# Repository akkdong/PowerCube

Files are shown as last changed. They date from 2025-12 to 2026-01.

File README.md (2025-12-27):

PowerCube
- Power Bank
- GPS
- Variometer
- Bluetooth

Goal: Charge mobile phone while transmitting GPS & Variometer data. It can also support BT connectivity.

<br>
<br>
<center>
  <p>
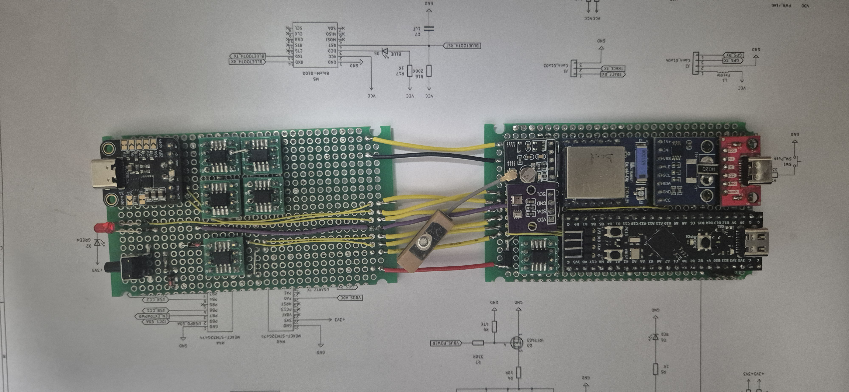
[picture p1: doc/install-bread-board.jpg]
    
  </p>
  <p>
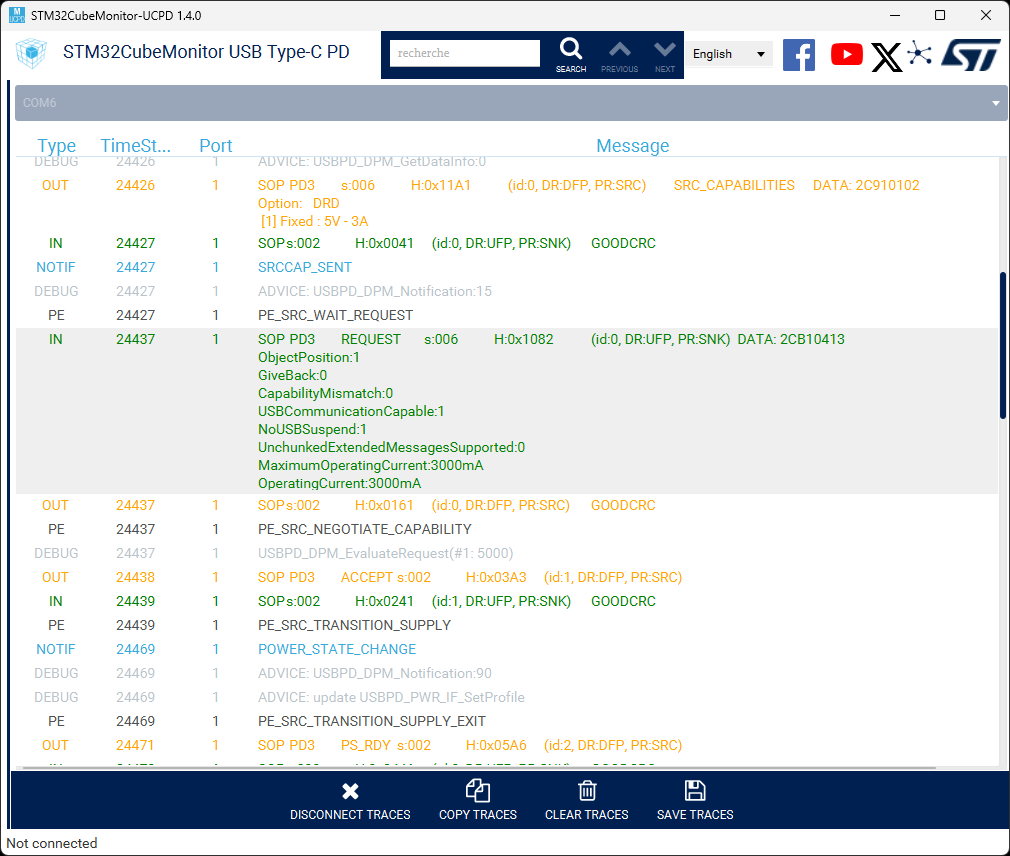
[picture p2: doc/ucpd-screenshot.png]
    
  </p>
  <p>
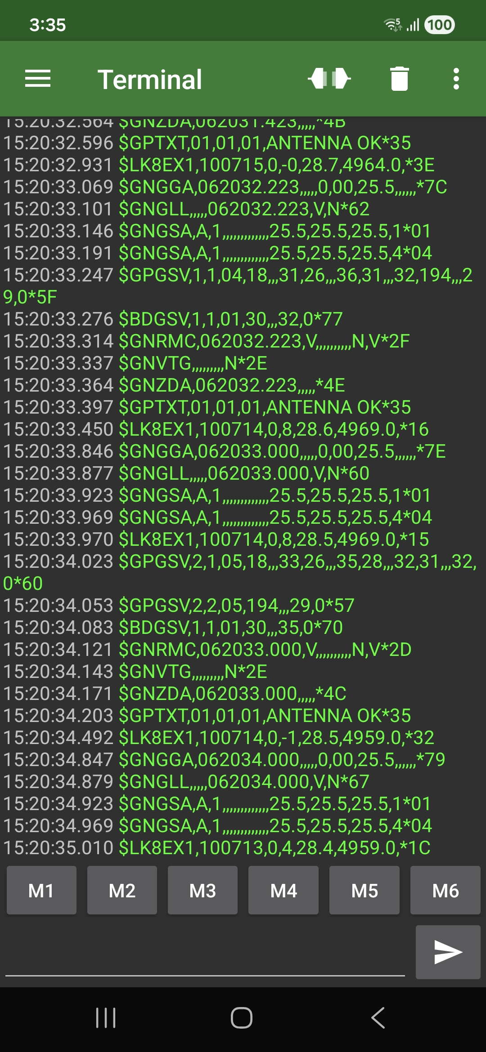
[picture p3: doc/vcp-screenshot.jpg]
    
  </p>
  <p>
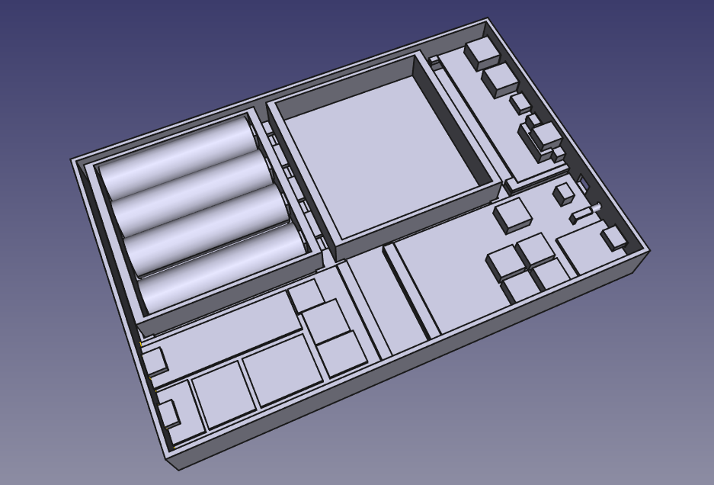
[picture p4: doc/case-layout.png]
    
  </p>
  <p>
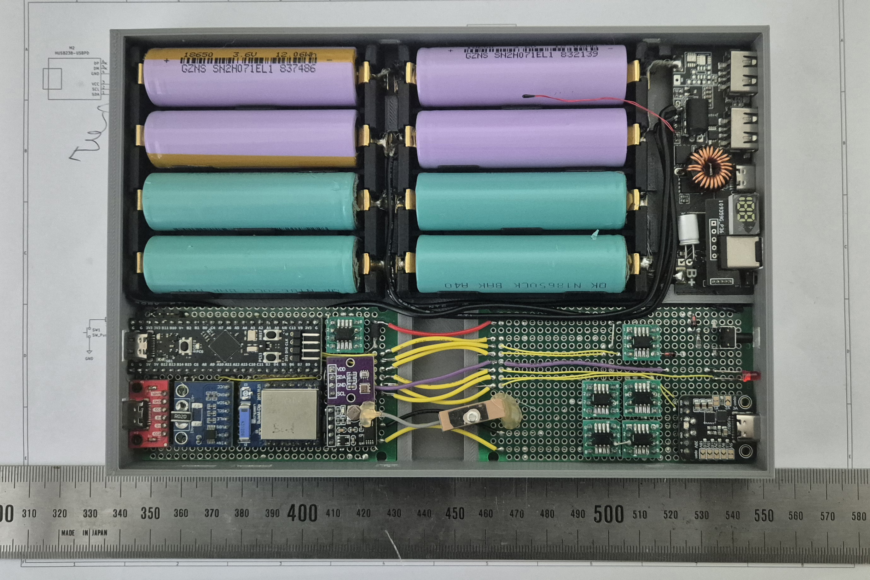
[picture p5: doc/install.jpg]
    
  </p>
</center>

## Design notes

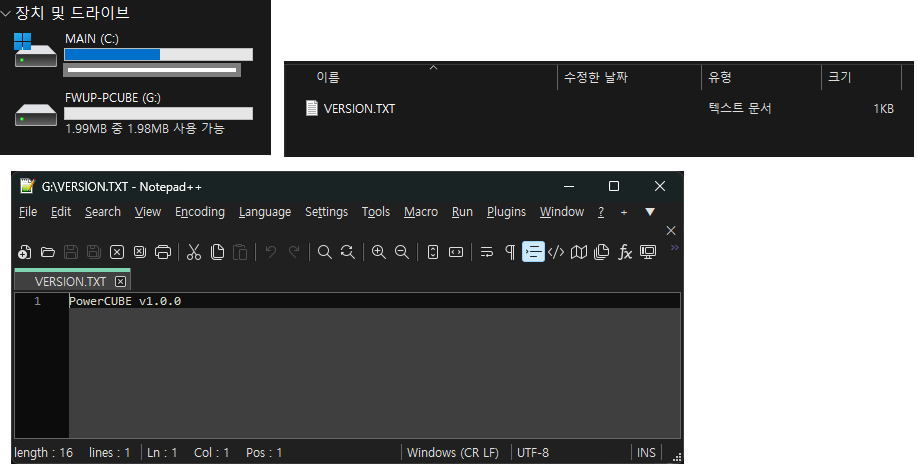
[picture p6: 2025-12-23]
doc/MSC-Bootloader.png

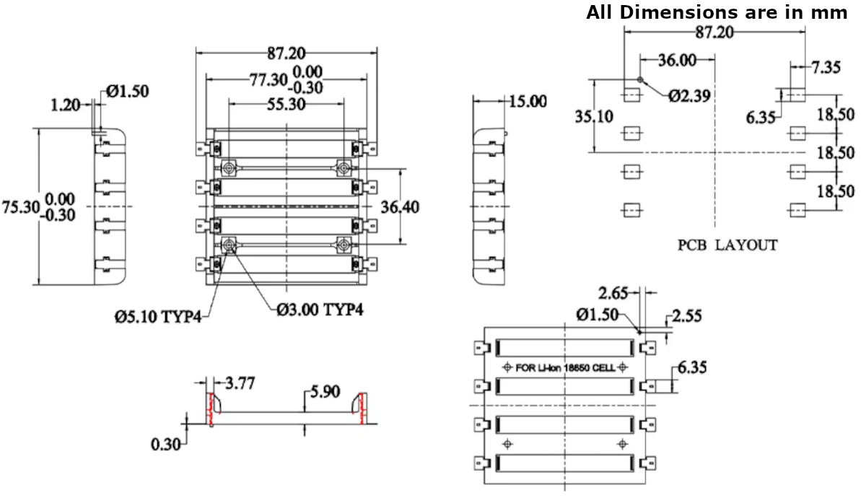
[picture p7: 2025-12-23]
doc/4_X_18650_Cell_Lithium_Ion_Battery_Holder_SMT_SMD_Socket_1_.jpg

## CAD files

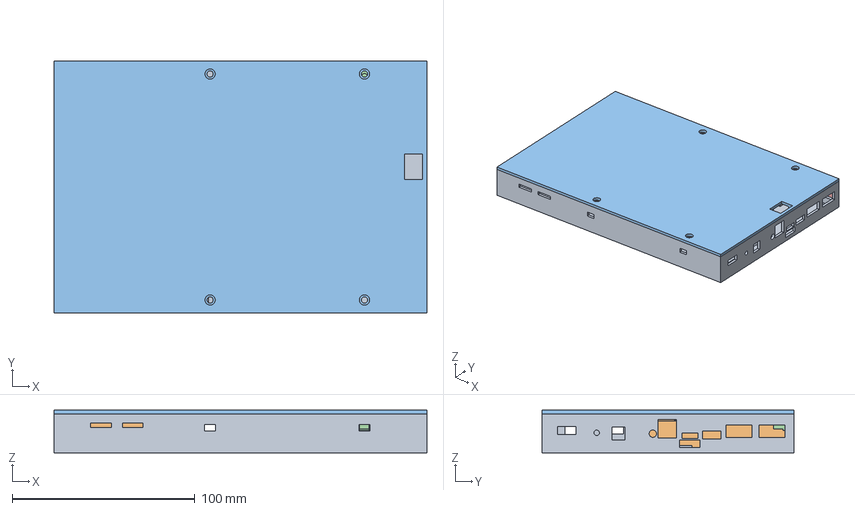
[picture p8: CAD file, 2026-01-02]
hw/enclosure/enclosure.FCStd
204.0 x 138.0 x 23.4 mm
ENCLOSUER-BODY
BatHolder-Left
ENCLOSUER-COVER
FixGuide
SPACER-A
SPACER-B

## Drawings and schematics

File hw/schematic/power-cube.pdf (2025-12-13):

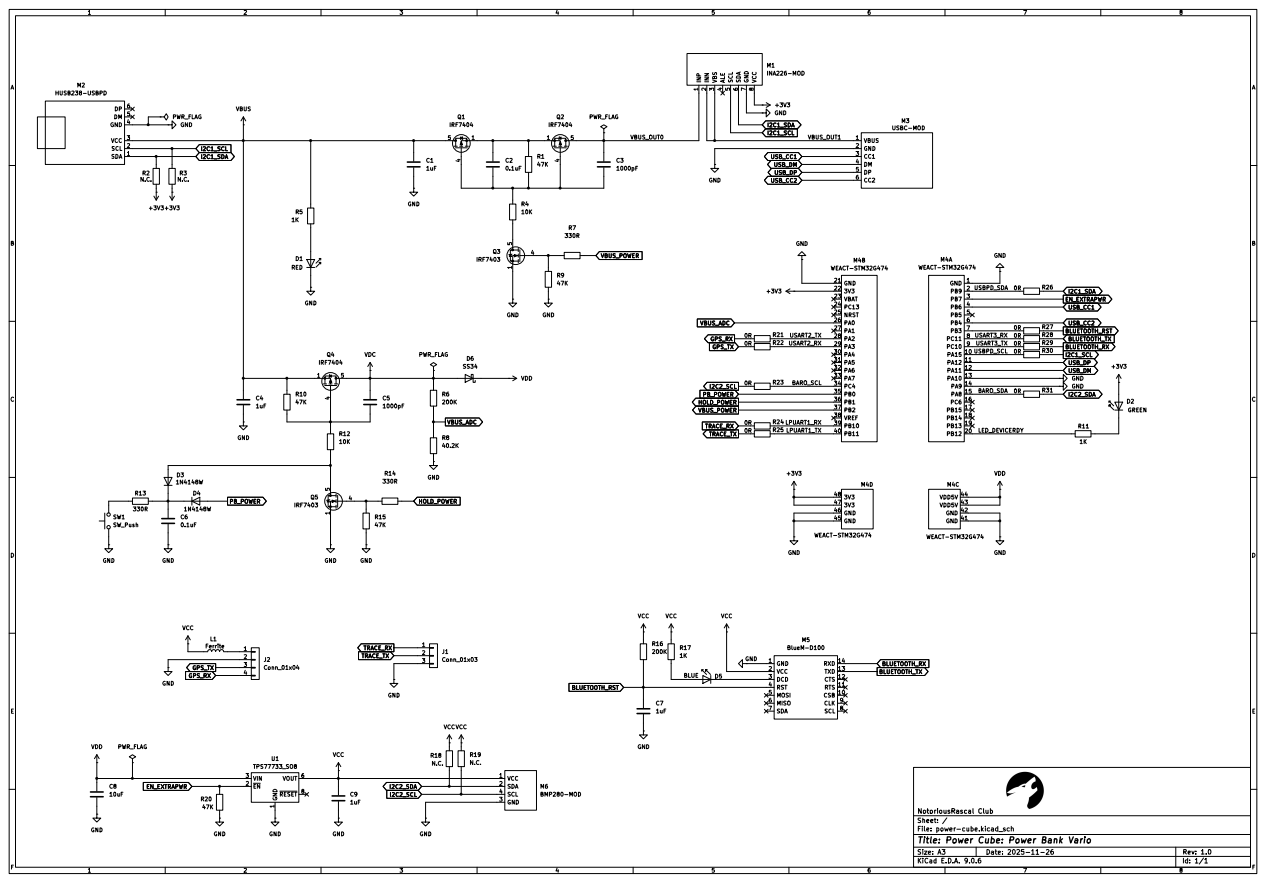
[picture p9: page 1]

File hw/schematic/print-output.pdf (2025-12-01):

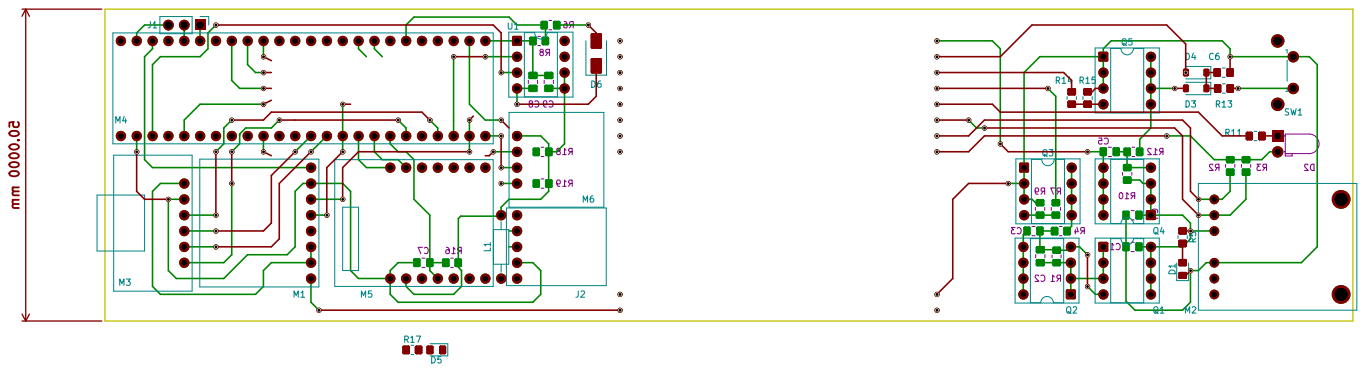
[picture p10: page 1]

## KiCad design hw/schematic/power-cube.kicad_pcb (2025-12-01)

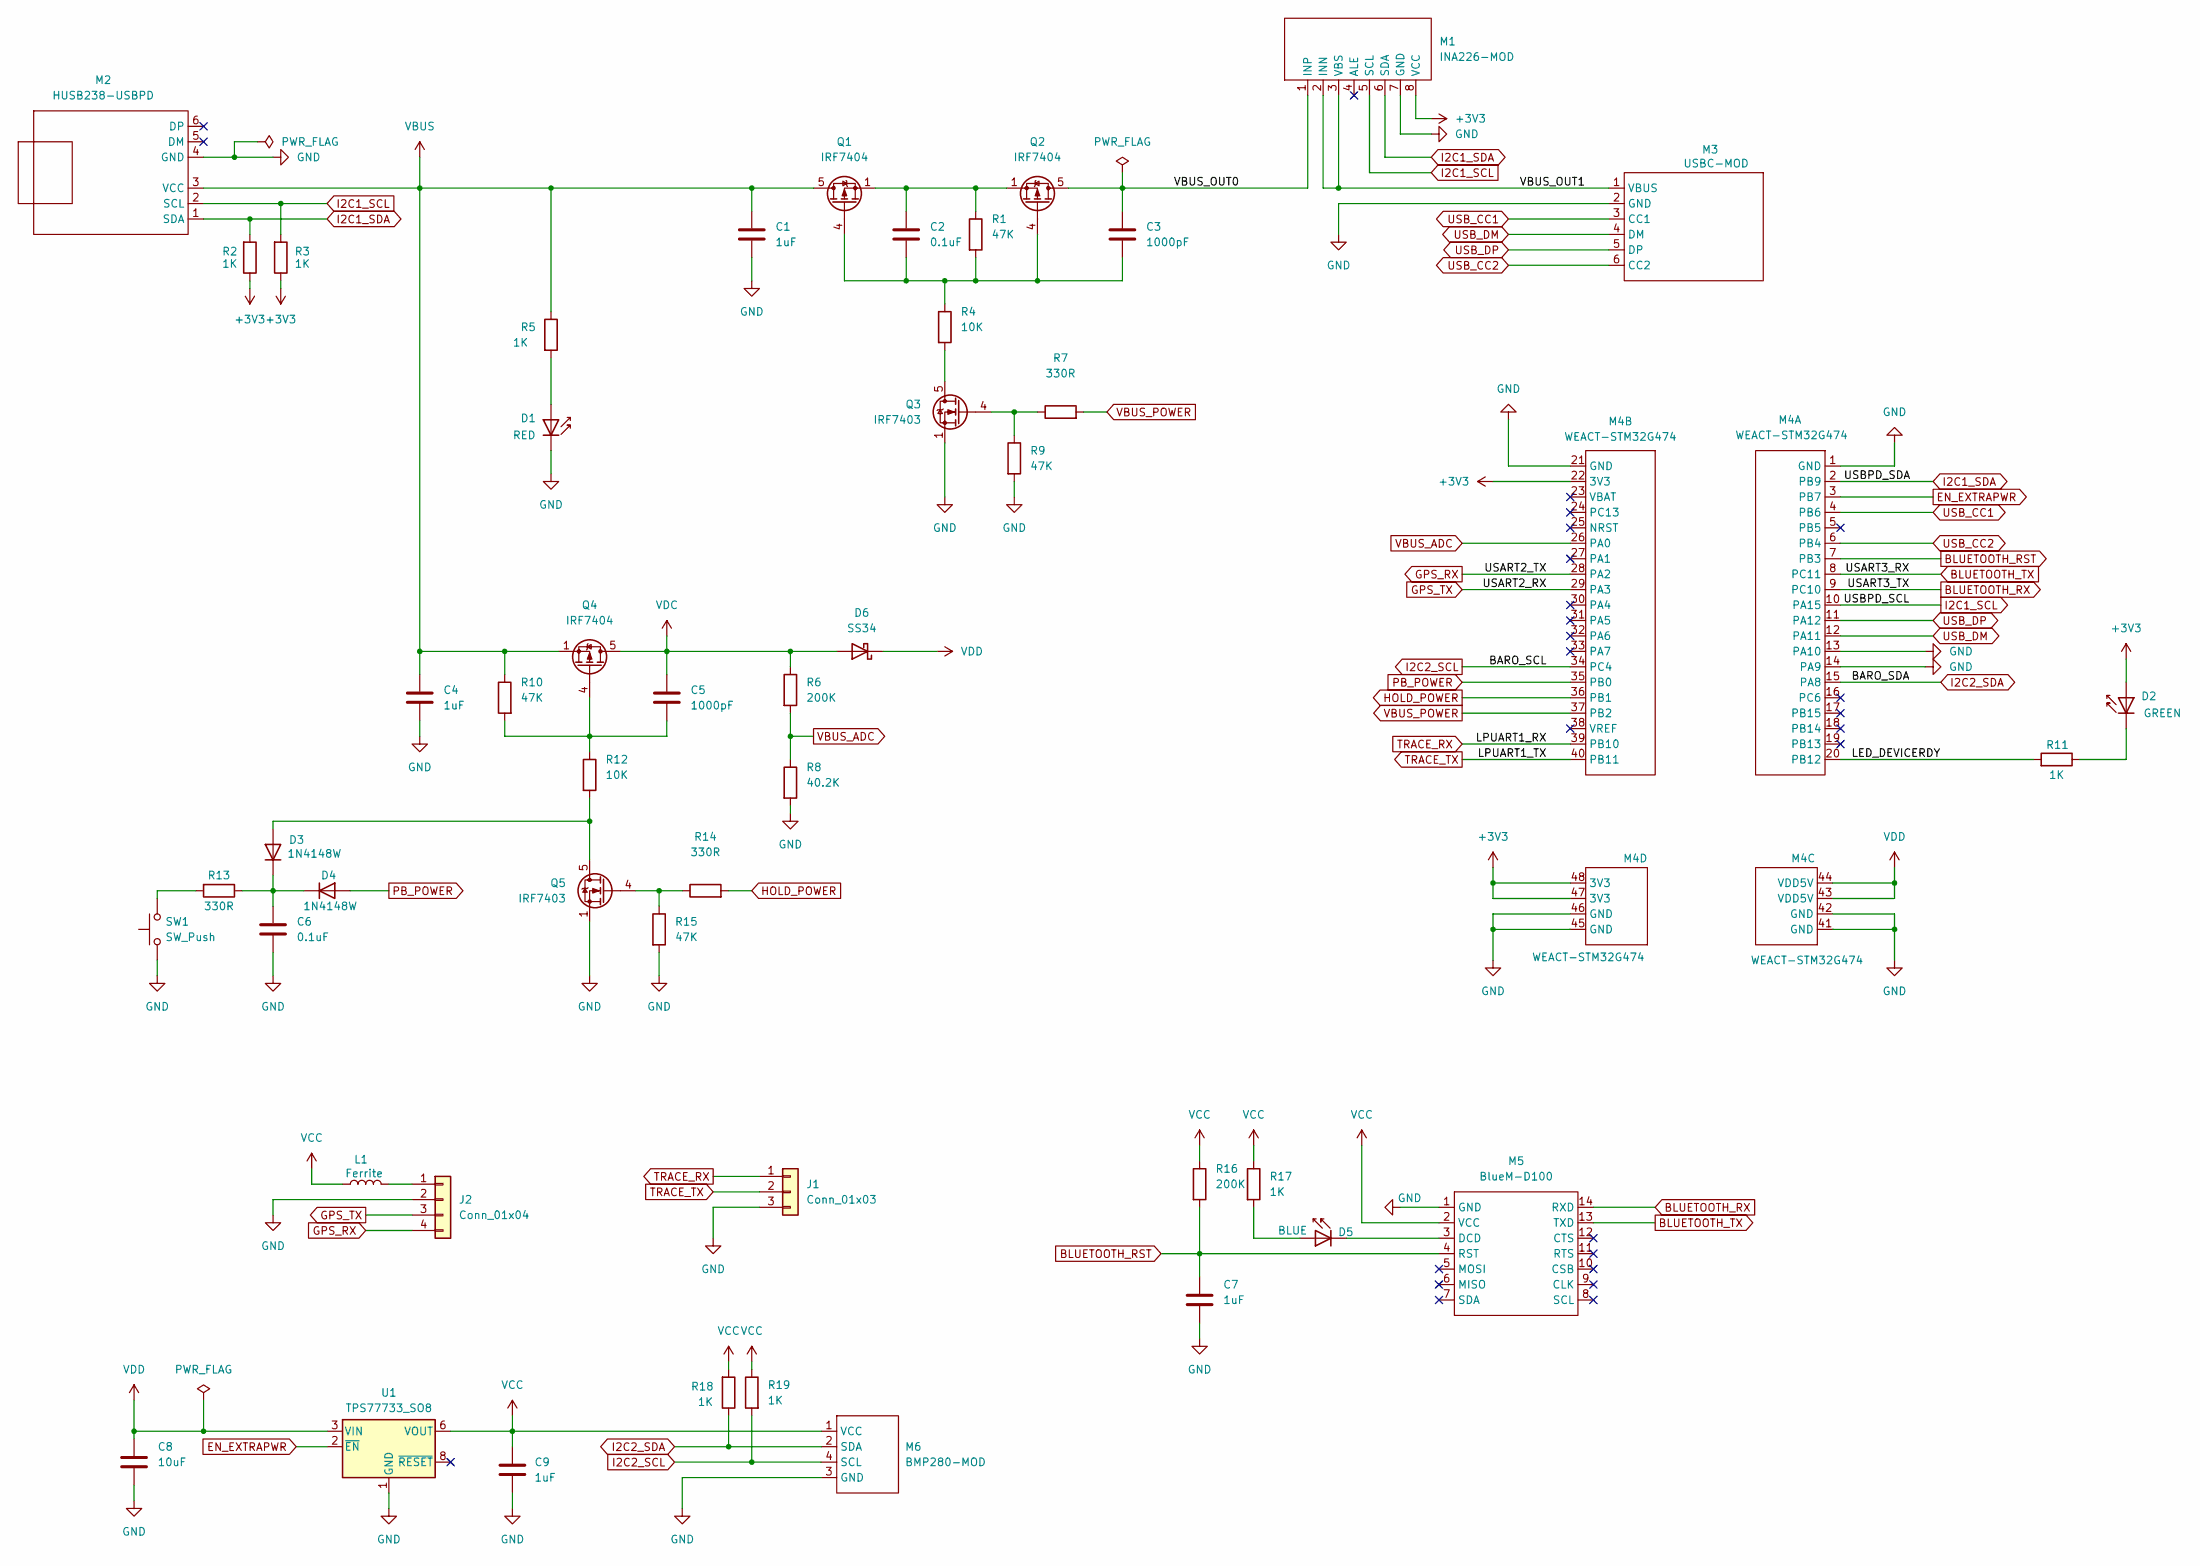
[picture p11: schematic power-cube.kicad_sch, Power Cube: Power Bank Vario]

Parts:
C1, C4, C7, C9: 1uF; C_0805_2012Metric_Pad1.18x1.45mm_HandSolder
C2, C6: 0.1uF; C_0805_2012Metric_Pad1.18x1.45mm_HandSolder
C3, C5: 1000pF; C_0805_2012Metric_Pad1.18x1.45mm_HandSolder
C8: 10uF; C_0805_2012Metric_Pad1.18x1.45mm_HandSolder
D1: RED; LED_0805_2012Metric_Pad1.15x1.40mm_HandSolder
D2: GREEN; LED_D3.0mm_Horizontal_O1.27mm_Z6.0mm
D3, D4: 1N4148W; D_SOD-123
D5: BLUE; LED_0805_2012Metric_Pad1.15x1.40mm_HandSolder
D6: SS34; D_SMA
J1: Conn_01x03; PinHeader_1x03_P2.54mm_Vertical
J2: Conn_01x04; GOOUUU-GPS-BD
L1: Ferrite; L_Axial_L5.3mm_D2.2mm_P10.16mm_Horizontal_Vishay_IM-1
M1: INA226-MOD
M2: HUSB238-USBPD
M3: USBC-MOD
M4: WEACT-STM32G474; WEACT-STM32G747
M5: BlueM-D100
M6: BMP280-MOD
Q1, Q2, Q4: IRF7404; DIP-8_W7.62mm_Socket
Q3, Q5: IRF7403; DIP-8_W7.62mm_Socket
R1, R9, R10, R15: 47K; R_0805_2012Metric_Pad1.20x1.40mm_HandSolder
R2, R3, R5, R11, R17, R18, R19: 1K; R_0805_2012Metric_Pad1.20x1.40mm_HandSolder
R4, R12: 10K; R_0805_2012Metric_Pad1.20x1.40mm_HandSolder
R6, R16: 200K; R_0805_2012Metric_Pad1.20x1.40mm_HandSolder
R7, R13, R14: 330R; R_0805_2012Metric_Pad1.20x1.40mm_HandSolder
R8: 40.2K; R_0805_2012Metric_Pad1.20x1.40mm_HandSolder
SW1: SW_Push; SW_Tactile_SPST_Angled_PTS645Vx39-2LFS
U1: TPS77733_SO8; DIP-8_W7.62mm_Socket

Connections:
+3V3: D2.2 (A), M1.8 (VCC), M4.22 (3V3), M4.47 (3V3), M4.48 (3V3), R2.1, R3.1
/LED_DEVICERDY: M4.20 (PB12), R11.2
/VBUS_OUT0: C3.2, M1.1 (INP), Q2.5 (D), Q2.6 (D), Q2.7 (D), Q2.8 (D)
/VBUS_OUT1: M1.2 (INN), M1.3 (VBS), M3.1 (VBUS)
BLUETOOTH_RST: C7.2, M4.7 (PB3), M5.4 (RST), R16.2
BLUETOOTH_RX: M4.9 (PC10), M5.14 (RXD)
BLUETOOTH_TX: M4.8 (PC11), M5.13 (TXD)
EN_EXTRAPWR: M4.3 (PB7), U1.2 (~EN)
GND: C1.1, C4.1, C6.1, C7.1, C8.1, C9.1, D1.1 (K), J1.3, J2.2, M1.7 (GND), M2.4 (GND), M3.2 (GND), M4.1 (GND), M4.13 (PA10), M4.14 (PA9), M4.21 (GND), M4.41 (GND), M4.42 (GND), M4.45 (GND), M4.46 (GND), M5.1 (GND), M6.3 (GND), Q3.1 (S), Q3.2 (S), Q3.3 (S), Q5.1 (S), Q5.2 (S), Q5.3 (S), R8.2, R9.2, R15.2, SW1.1, U1.1 (GND)
GPS_RX: J2.4, M4.28 (PA2)
GPS_TX: J2.3, M4.29 (PA3)
HOLD_POWER: M4.36 (PB1), R14.2
I2C1_SCL: M1.5 (SCL), M2.2 (SCL), M4.10 (PA15), R3.2
I2C1_SDA: M1.6 (SDA), M2.1 (SDA), M4.2 (PB9), R2.2
I2C2_SCL: M4.34 (PC4), M6.4 (SCL), R19.2
I2C2_SDA: M4.15 (PA8), M6.2 (SDA), R18.1
unnamed: C2.2, Q1.1 (S), Q1.2 (S), Q1.3 (S), Q2.1 (S), Q2.2 (S), Q2.3 (S), R1.1
unnamed: D1.2 (A), R5.2
unnamed: D2.1 (K), R11.1
unnamed: D3.2 (A), Q5.5 (D), Q5.6 (D), Q5.7 (D), Q5.8 (D), R12.2
unnamed: C6.2, D3.1 (K), D4.1 (K), R13.1
unnamed: D5.2 (A), R17.2
unnamed: D5.1 (K), M5.3 (DCD)
unnamed: J2.1, L1.1
unnamed: C2.1, C3.1, Q1.4 (G), Q2.4 (G), R1.2, R4.1
unnamed: Q3.5 (D), Q3.6 (D), Q3.7 (D), Q3.8 (D), R4.2
unnamed: Q3.4 (G), R7.1, R9.1
unnamed: C5.1, Q4.4 (G), R10.2, R12.1
unnamed: Q5.4 (G), R14.1, R15.1
unnamed: R13.2, SW1.2
PB_POWER: D4.2 (A), M4.35 (PB0)
TRACE_RX: J1.1, M4.39 (PB10)
TRACE_TX: J1.2, M4.40 (PB11)
USB_CC1: M3.3 (CC1), M4.4 (PB6)
USB_CC2: M3.6 (CC2), M4.6 (PB4)
USB_DM: M3.4 (DM), M4.12 (PA11)
USB_DP: M3.5 (DP), M4.11 (PA12)
VBUS: C1.2, C4.2, M2.3 (VCC), Q1.5 (D), Q1.6 (D), Q1.7 (D), Q1.8 (D), Q4.1 (S), Q4.2 (S), Q4.3 (S), R5.1, R10.1
VBUS_ADC: M4.26 (PA0), R6.2, R8.1
VBUS_POWER: M4.37 (PB2), R7.2
VCC: C9.2, L1.2, M5.2 (VCC), M6.1 (VCC), R16.1, R17.1, R18.2, R19.1, U1.5 (VOUT), U1.6 (VOUT)
VDC: C5.2, D6.2 (A), Q4.5 (D), Q4.6 (D), Q4.7 (D), Q4.8 (D), R6.1
VDD: C8.2, D6.1 (K), M4.43 (VDD5V), M4.44 (VDD5V), U1.3 (VIN), U1.4 (VIN)

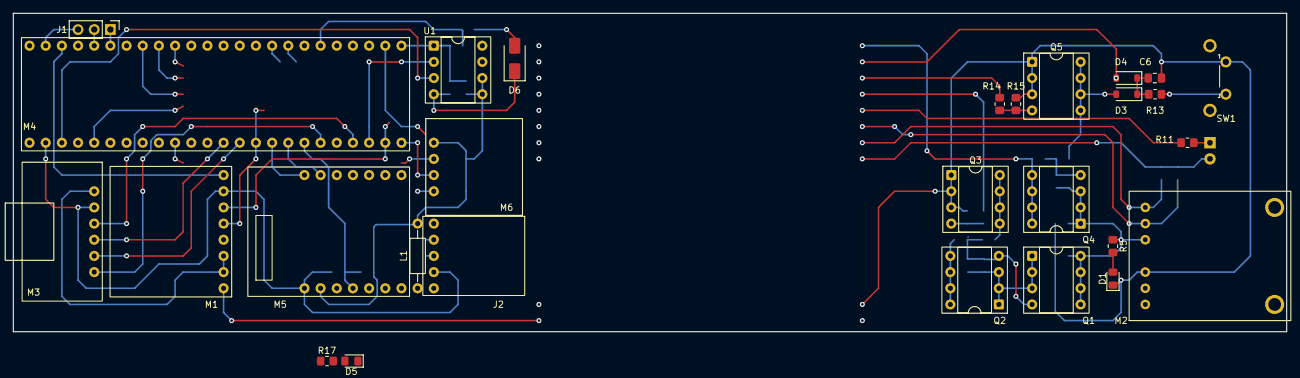
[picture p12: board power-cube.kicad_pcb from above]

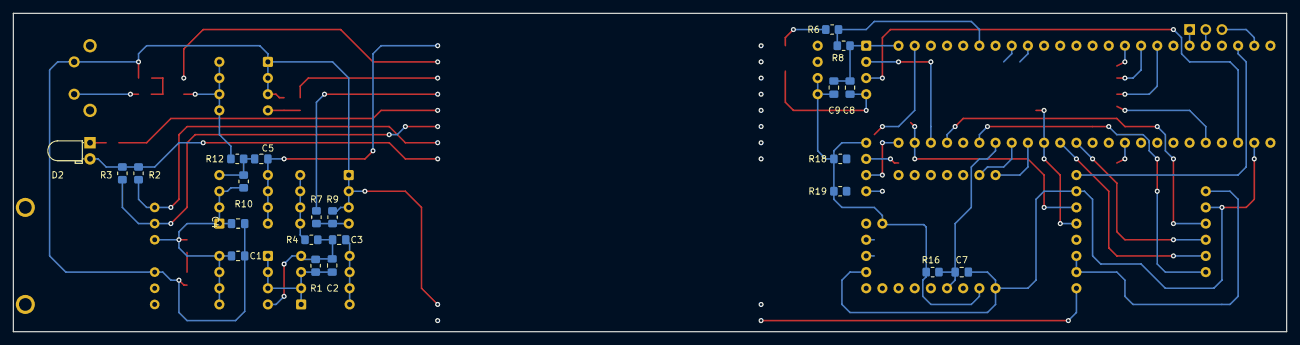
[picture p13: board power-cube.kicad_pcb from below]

Board: 2 copper layers, 200.0 x 50.0 mm, 50 parts (22 on the bottom side), 43 nets.

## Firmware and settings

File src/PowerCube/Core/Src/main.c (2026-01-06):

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
/* Includes ------------------------------------------------------------------*/
#include "main.h"
#include "cmsis_os.h"
#include "usbpd.h"
#include "usb_device.h"

ADC_HandleTypeDef hadc1;
DMA_HandleTypeDef hdma_adc1;

I2C_HandleTypeDef hi2c1;
I2C_HandleTypeDef hi2c2;

#if 0
UART_HandleTypeDef huart2;
UART_HandleTypeDef huart3;
#endif

osThreadId defaultTaskHandle;
void SystemClock_Config(void);
void MX_GPIO_Init(void);
void MX_DMA_Init(void);
void MX_LPUART1_UART_Init(void);
void MX_UCPD1_Init(void);
void MX_I2C1_Init(void);
void MX_I2C2_Init(void);
void MX_USART2_UART_Init(UART_HandleTypeDef *pHandle);
void MX_ADC1_Init(void);
void MX_USART3_UART_Init(UART_HandleTypeDef *pHandle);
void StartDefaultTask(void const * argument);

/* USER CODE BEGIN 0 */

typedef struct __Watermark
{
	uint32_t code;
	const char info[32];
} Watermark;


__attribute__((section(".user_watermark")))
const Watermark _watermark = {
	.code = 0xDEADBEEF,
	.info = FW_VERSION_STRING,
};


/* USER CODE END 0 */

/**
  * @brief  The application entry point.
  * @retval int
  */
int MAIN_OBSOLETE(void)
{

  /* MCU Configuration--------------------------------------------------------*/

  /* Reset of all peripherals, Initializes the Flash interface and the Systick. */
  HAL_Init();

  /* Configure the system clock */
  SystemClock_Config();

  /* Initialize all configured peripherals */
  MX_GPIO_Init();
  MX_DMA_Init();
  MX_LPUART1_UART_Init();
  MX_UCPD1_Init();
  MX_I2C1_Init();
  MX_I2C2_Init();
  /*
  MX_USART2_UART_Init(&huart2;
  */
  MX_ADC1_Init();
  /*
  MX_USART3_UART_Init(&huart3);
  */
  /* USBPD initialization ---------------------------------*/
  MX_USBPD_Init();

  /* USER CODE BEGIN RTOS_MUTEX */
  /* add mutexes, ... */
  /* USER CODE END RTOS_MUTEX */

  /* USER CODE BEGIN RTOS_SEMAPHORES */
  /* add semaphores, ... */
  /* USER CODE END RTOS_SEMAPHORES */

  /* USER CODE BEGIN RTOS_TIMERS */
  /* start timers, add new ones, ... */
  /* USER CODE END RTOS_TIMERS */

  /* USER CODE BEGIN RTOS_QUEUES */
  /* add queues, ... */
  /* USER CODE END RTOS_QUEUES */

  /* Create the thread(s) */
  /* definition and creation of defaultTask */
  osThreadDef(defaultTask, StartDefaultTask, osPriorityNormal, 0, 128);
  defaultTaskHandle = osThreadCreate(osThread(defaultTask), NULL);

  /* USER CODE BEGIN RTOS_THREADS */
  /* add threads, ... */
  /* USER CODE END RTOS_THREADS */

  /* Start scheduler */
  osKernelStart();

  /* We should never get here as control is now taken by the scheduler */

  /* Infinite loop */
  /* USER CODE BEGIN WHILE */
  while (1)
  {
    /* USER CODE END WHILE */

    /* USER CODE BEGIN 3 */
  }
  /* USER CODE END 3 */
}

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
/* USER CODE BEGIN Header_StartDefaultTask */
/**
  * @brief  Function implementing the defaultTask thread.
  * @param  argument: Not used
  * @retval None
  */


/* USER CODE END Header_StartDefaultTask */
void StartDefaultTask(void const * argument)
{
  /* init code for USB_Device */
  MX_USB_Device_Init();
  /* USER CODE BEGIN 5 */

  /* Infinite loop */
  for(;;)
  {
  }

  /* USER CODE END 5 */
}

/**
  * @brief  This function is executed in case of error occurrence.
  * @retval None
  */
void Error_Handler(void)
{
  /* USER CODE BEGIN Error_Handler_Debug */
  /* User can add his own implementation to report the HAL error return state */
  __disable_irq();
  while (1)
  {
  }
  /* USER CODE END Error_Handler_Debug */
}
#ifdef USE_FULL_ASSERT
/**
  * @brief  Reports the name of the source file and the source line number
  *         where the assert_param error has occurred.
  * @param  file: pointer to the source file name
  * @param  line: assert_param error line source number
  * @retval None
  */
void assert_failed(uint8_t *file, uint32_t line)
{
  /* USER CODE BEGIN 6 */
  /* User can add his own implementation to report the file name and line number,
     ex: printf("Wrong parameters value: file %s on line %d\r\n", file, line) */
  /* USER CODE END 6 */
}
#endif /* USE_FULL_ASSERT */

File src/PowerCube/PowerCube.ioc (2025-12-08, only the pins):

Mcu.UserName=STM32G474CEUx
PA0.GPIO_Label=VBUS_ADC
PA0.Signal=ADC1_IN1
PA10.Signal=UCPD1_DBCC2
PA11.Signal=USB_DM
PA12.Signal=USB_DP
PA13.Signal=SYS_JTMS-SWDIO
PA14.Signal=SYS_JTCK-SWCLK
PA15.GPIO_Label=USBPD_I2C_SCL
PA15.Signal=I2C1_SCL
PA2.GPIO_Label=GPS_RX
PA2.Signal=USART2_TX
PA3.GPIO_Label=GPS_TX
PA3.Signal=USART2_RX
PA8.GPIO_Label=BARO_I2C_SDA
PA8.Signal=I2C2_SDA
PA9.Signal=UCPD1_DBCC1
PB0.GPIO_Label=PB_POWER
PB0.Signal=GPXTI0
PB1.GPIO_Label=HOLD_POWER
PB1.Signal=GPIO_Output
PB10.GPIO_Label=TRACE_RX
PB10.Signal=LPUART1_RX
PB11.GPIO_Label=TRACE_TX
PB11.Signal=LPUART1_TX
PB12.GPIO_Label=LED_DEVICERDY
PB12.Signal=GPIO_Output
PB2.GPIO_Label=VBUS_POWER
PB2.Signal=GPIO_Output
PB3.GPIO_Label=BLUETOOTH_RST
PB3.Signal=GPIO_Output
PB4.Signal=UCPD1_CC2
PB6.Signal=UCPD1_CC1
PB7.GPIO_Label=EN_EXTRAPWR
PB7.Signal=GPIO_Output
PB9.GPIO_Label=USBPD_I2C_SDA
PB9.Signal=I2C1_SDA
PC10.GPIO_Label=BLUETOOTH_RX
PC10.Signal=USART3_TX
PC11.GPIO_Label=BLUETOOTH_TX
PC11.Signal=USART3_RX
PC13.GPIO_Label=PB_BOARD
PC13.Signal=GPXTI13
PC14-OSC32_IN.Signal=RCC_OSC32_IN
PC15-OSC32_OUT.Signal=RCC_OSC32_OUT
PC4.GPIO_Label=BARO_I2C_SCL
PC4.Signal=I2C2_SCL
PC6.GPIO_Label=LED_BOARD
PC6.Signal=GPIO_Output
PF0-OSC_IN.Signal=RCC_OSC_IN
PF1-OSC_OUT.Signal=RCC_OSC_OUT

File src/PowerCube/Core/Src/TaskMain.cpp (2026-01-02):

/*
 * Task.cpp
 *
 *  Created on: 2025. 12. 9.
 *      Author: akkdong
 */


#include "Task.h"
#include "usbpd.h"
#include "usb_device.h"


#include <stdio.h>
#include <stdlib.h>
#include <string.h>

#include "HardwareSerial.h"
#include "USBSerial.h"
#include "BMP280.h"
#include "INA226.h"
#include "HUSB238.h"
#include "AHT20.H"
#include "IOPin.h"
#include "BeaconIndicator.h"

#include "BluetoothHandler.h"
#include "LineBuffer.h"
#include "VarioSentence.h"

#include "nmea/NmeaParser.h"


//
//
//

#define ROUTE_TO_BLUETOOTH	1


//
//
//

extern INA226 ina226;
extern HUSB238 husb238;

extern BluetoothHandler bt;
extern BeaconIndicator beacon;

extern DeviceState devState;

extern osTimerId shutdownTimerId;
extern osMessageQId mainQueueId;


//
//
//

const int maxBufSize = 96; // A standard GPS NMEA 0183 sentence has a maximum size of 82 characters

char bufSerial2[maxBufSize];
char bufVario[maxBufSize];

LineBuffer lineBuf(bufSerial2, maxBufSize);
LineBuffer varioBuf(bufVario, maxBufSize);

VarioSentence varioSentense(VSENTENCE_LK8);
NmeaParser nmeaParser;



////////////////////////////////////////////////////////////////////////////
//

void flushVarioSentence()
{
	// make vario sentence
	varioSentense.begin(
			devState.altitude,
			devState.varioSpeed,
			devState.temperature,
			devState.pressure,
			devState.voltage);

	// copy to line-buffer
	varioBuf.reset();
	while (varioSentense.available())
	{
		varioBuf.push(varioSentense.read());

		if (varioBuf.hasCompleteLine() && varioBuf.getLength() > 0)
			break;
	}

	// transfer a sentence to usb-serial and/or bt
	if (SerialUSB)
		SerialUSB.puts(varioBuf, true);

	#if ROUTE_TO_BLUETOOTH
	bt.puts(varioBuf, true);
	#endif
}



////////////////////////////////////////////////////////////////////////////
//

void MainTaskProc(void const * argument)
{
	//
	beacon.begin();
	beacon.off(BeaconIndicator::BeaconType::Body);
	beacon.off(BeaconIndicator::BeaconType::Board);

	ioPin[IOPIN_POWER_DEVICE].on();
	ioPin[IOPIN_POWER_PERIPH].on();
	ioPin[IOPIN_POWER_VBUS].off();

	//
	bt.begin();


	//
	memset(&devState, 0, sizeof(devState));

	devState.btnState[PB_BODY] = ioPin[IOPIN_BODY_INPUT].isOn() ? PB_PRESSED : PB_RELEASED;
	devState.btnState[PB_BOARD] = ioPin[IOPIN_BOARD_INPUT].isOn() ? PB_PRESSED : PB_RELEASED;

	lineBuf.reset();
	nmeaParser.reset();

	//

	beacon.on(BeaconIndicator::BeaconType::Body);
	beacon.blink(BeaconIndicator::BeaconType::Board, 500);


	/* Infinite loop */
	for(;;)
	{
		//
		if (Serial2.available() > 0)
		{
			int ch = Serial2.read();
			lineBuf.push(ch);

			if (nmeaParser.update(ch) > 0) // 1: GPS, 2: VARIO(UNUSED), 3: KEY(UNUSED)
			{
				devState.latitude = nmeaParser.getLatitude();
				devState.longitude = nmeaParser.getLongitude();
				devState.altitude = nmeaParser.getAltitude();
				devState.speed = nmeaParser.getSpeed();
				devState.now = nmeaParser.getDateTime();

				// do what?
			}
		}

		if (bt.update() > 0)
		{
			const char *str = bt.getReceiveData();
			if (strncmp(str, "CONNECT", strlen("CONNECT")) == 0)
				bt.setState(BluetoothHandler::CONNECTED);
			else if (strncmp(str, "DISCONNECT", strlen("DISCONNECT")) == 0)
				bt.setState(BluetoothHandler::PENDING);

			bt.clearData();
		}

		//
		osEvent event = osMessageGet(mainQueueId, 0);
		if (event.status == osEventMessage)
		{
			// message format: x--- abcd
			//   -x: updated target: adc, vario, timer, exti irq
			//   -abcd: updated data: target specific
			//

			uint32_t data = event.value.v & 0x0000FFFF;

			if (event.value.v & MQ_MSRC_ADCTASK) // message from adc-task
			{
				if (data & 1) // updated input voltage
				{
					TRACE("IVBUS,V,%u\r\n", devState.voltage);
				}

				if (data & 2)
				{
					TRACE("OVBUS,V,%u,C,%u,VS,%u\r\n", devState.vbusVoltage, devState.vbusCurrent, (uint32_t)(devState.shuntVoltage / 0.02));
				}
			}
			else if (event.value.v & MQ_MSRC_VARIOTASK) // message from vario-task
			{
#if DEBUG_BMP280 || 1
				TRACE("BMP280,T,%d,P,%d\r\n", (int)devState.temperature, (int)devState.pressure);
#endif
#if ENABLE_AHT20
				TRACE("AHT20,T,%d,H,%d\r\n", (int)devState.temperature, (int)devState.humidity);
#endif

				flushVarioSentence();
			}
			else if (event.value.v & MQ_MSRC_SHUTDOWNTIMER) // message from timer-task
			{
				TRACE("SHUTDOWN\r\n");
				osDelay(200);

				beacon.off(BeaconIndicator::BeaconType::Body);
				beacon.blink(BeaconIndicator::BeaconType::Board, 200);
				ioPin[IOPIN_POWER_DEVICE].off();
				/*
				ioPin[IOPIN_POWER_PERIPH].off();
				*/
				break;
			}
			else if (event.value.v & MQ_MSRC_EXTINTR) // message from exti irq
			{
				if (devState.btnUpdateMask & (1 << PB_BODY))
				{
					TRACE("BTN,BODY,%s\r\n", devState.btnState[PB_BODY] == PB_PRESSED ? "On" : "Off");
					devState.btnUpdateMask &= ~(1 << PB_BODY);

					if (devState.btnState[PB_BODY] == PB_PRESSED)
						osTimerStart(shutdownTimerId, 4000);
					else
						osTimerStop(shutdownTimerId);

				}

				if (devState.btnUpdateMask & (1 << PB_BOARD))
				{
					TRACE("BTN,BOARD,%s\r\n", devState.btnState[PB_BOARD] == PB_PRESSED ? "On" : "Off");
					devState.btnUpdateMask &= ~(1 << PB_BODY);
				}

				devState.btnUpdateMask = 0;
			}
		}

		if (lineBuf.hasCompleteLine() && lineBuf.getLength() > 0)
		{
			// parse NMEA sentence & forward to usb-serial and/or blue-tooth
			//
			// parse NMEA
			// ....
			//

#if USE_NMEAFILTER
			// filtering NMEA sentence
			const char *line = (const char *)lineBuf;
#if BLOCK_SATELLITE_INFO
			// $XXGSx : block GSV, GSA
			if (line[3] != 'G' || line[4] != 'S')
#elif BLOCK_TAKLERID_BD
			if (line[1] != 'B' || line[2] != 'D')
#endif
#endif
			{
#if USE_NMEAFILTER
#if FAKE_GN2GP
				if (line[1] == 'G' && line[2] == 'N')
				{
					char *ptr = (char *)line;
					ptr[2] = 'P';
				}
#endif
#endif

				if (SerialUSB)
					SerialUSB.puts(lineBuf, true);
				#if ROUTE_TO_BLUETOOTH
				bt.puts(lineBuf, true);
				#endif
			}

			lineBuf.reset();
		}
	}

	//
	while(1)
		osDelay(100);
}

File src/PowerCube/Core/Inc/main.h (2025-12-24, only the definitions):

#define PB_BOARD_Pin GPIO_PIN_13
#define PB_BOARD_GPIO_Port GPIOC
#define PB_BOARD_EXTI_IRQn EXTI15_10_IRQn
#define VBUS_ADC_Pin GPIO_PIN_0
#define VBUS_ADC_GPIO_Port GPIOA
#define GPS_RX_Pin GPIO_PIN_2
#define GPS_RX_GPIO_Port GPIOA
#define GPS_TX_Pin GPIO_PIN_3
#define GPS_TX_GPIO_Port GPIOA
#define BARO_I2C_SCL_Pin GPIO_PIN_4
#define BARO_I2C_SCL_GPIO_Port GPIOC
#define PB_POWER_Pin GPIO_PIN_0
#define PB_POWER_GPIO_Port GPIOB
#define PB_POWER_EXTI_IRQn EXTI0_IRQn
#define HOLD_POWER_Pin GPIO_PIN_1
#define HOLD_POWER_GPIO_Port GPIOB
#define VBUS_POWER_Pin GPIO_PIN_2
#define VBUS_POWER_GPIO_Port GPIOB
#define TRACE_RX_Pin GPIO_PIN_10
#define TRACE_RX_GPIO_Port GPIOB
#define TRACE_TX_Pin GPIO_PIN_11
#define TRACE_TX_GPIO_Port GPIOB
#define LED_DEVICERDY_Pin GPIO_PIN_12
#define LED_DEVICERDY_GPIO_Port GPIOB
#define LED_BOARD_Pin GPIO_PIN_6
#define LED_BOARD_GPIO_Port GPIOC
#define BARO_I2C_SDA_Pin GPIO_PIN_8
#define BARO_I2C_SDA_GPIO_Port GPIOA
#define USBPD_I2C_SCL_Pin GPIO_PIN_15
#define USBPD_I2C_SCL_GPIO_Port GPIOA
#define BLUETOOTH_RX_Pin GPIO_PIN_10
#define BLUETOOTH_RX_GPIO_Port GPIOC
#define BLUETOOTH_TX_Pin GPIO_PIN_11
#define BLUETOOTH_TX_GPIO_Port GPIOC
#define BLUETOOTH_RST_Pin GPIO_PIN_3
#define BLUETOOTH_RST_GPIO_Port GPIOB
#define EN_EXTRAPWR_Pin GPIO_PIN_7
#define EN_EXTRAPWR_GPIO_Port GPIOB
#define USBPD_I2C_SDA_Pin GPIO_PIN_9
#define USBPD_I2C_SDA_GPIO_Port GPIOB

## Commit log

2025-12-01 update pdf schematic
    [power-cube.kicad_sch]
2025-12-01 mod schematic
    [power-cube.kicad_pcb, power-cube.kicad_sch]
2025-12-01 add extra-power enable
2025-12-07 add source
    [power-cube.kicad_sch]
2025-12-08 sensor: BMP280, INA226
2025-12-10 sensor AHT20 (un-tested) BT handler (TBD) fixed RTOS configuration
2025-12-10 usbpd implement (TBD, not working)
    [usbpd_pdo_defs.h]
2025-12-12 Implement USBPD basic function
    - Supply Fixed 5V
    - UFP date role swap --> Virtual COM Device
    [BSP_usbpd_pwr_user.c]
2025-12-13 use message-q
    [power-cube.kicad_sch]
2025-12-14 usb2serial : clone of Arduino
2025-12-15 migrate to TCPP 4.2.0
    - usbpd & utilities (GUI_INTEFACE, TRACER_EMB)
    - change task priority to make GUI work
2025-12-17 enclosure (TBD)
    [enclosure.FCStd]
2025-12-19 Add case layout image to README
2025-12-27 enclosure (done)
    [enclosure.FCStd]
2026-01-02 Minor update - bootloader: enter user application if there is no action - increase buffer/heap size - wait baro wake up
    [enclosure.FCStd]
2026-01-06 hold down power key when booting

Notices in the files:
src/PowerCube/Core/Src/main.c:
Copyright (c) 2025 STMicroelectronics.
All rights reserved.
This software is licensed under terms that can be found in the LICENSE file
